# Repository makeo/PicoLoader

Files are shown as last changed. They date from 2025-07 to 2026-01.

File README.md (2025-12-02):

# PicoLoader
This is an ODE-based modchip for the Nintendo GameCube to boot homebrew.\
Its price and functionality are very similar to [PicoBoot](https://github.com/webhdx/PicoBoot) but it has multiple advantages.

Join the [Discord server](https://discord.gg/YtA9aU3BKZ) to get support and discuss the mod!

## How does it work?
This mod works by emulating a disk drive during boot, executing a homebrew app, and afterwards re-enabling the disk drive.\
This is achieved using a flex PCB similar to FlippyDrive.
However, it is not a full optical drive emulator and only allows executing small homebrew apps (e.g. [swiss](https://github.com/emukidid/swiss-gc)) from flash just like PicoBoot.
To access files on an SD card, you need an SDGecko, SD2SP2, or similar adapter, which can be purchased separately.

## Features
- Open source
- You can keep the disk drive
- Simple to boot most homebrew apps using an [online converter](https://makeo.github.io/PicoLoader/converter/)
- No permanent modifications to the GameCube
- [3D printed plug](https://github.com/makeo/PicoLoader/raw/refs/heads/main/mount/Drive_PlugV1.1.stl) for installs without a disk drive 
- Easy to remove
- Running Pico at 200Mhz for better compatibility with clone boards

#### Soldered Variant
- Cheap and easy to get components (Raspberry Pi Pico/Pico 2 + Flex PCB + Diode)
- Readily available
- No soldering directly to the GameCube
- Easy soldering
- Alternative install options: [Panasonic Q](https://github.com/makeo/PicoLoader/wiki/4.-Advanced-Section#panasonic-q-install-option), [low-profile](https://github.com/makeo/PicoLoader/wiki/4.-Advanced-Section#low-profile-install-option)

#### Solderless Variant
- No soldering
- Easily replaceable flex PCB
- Pre-programmed with PicoLoader firmware and [Swiss](https://github.com/emukidid/swiss-gc)
> [!TIP]
> You can buy the solderless and normal variant from [store.makstech.io](https://store.makstech.io/).

## Planned Features
*cricket sound*

## Installation & Documentation
> [!IMPORTANT]
> Please follow the [installation instructions](https://makeo.github.io/PicoLoader/) in the wiki.\
> When not following the instructions, there is a chance of breaking the flex PCB during installation.

Get started by looking at the 📖[Wiki](https://github.com/makeo/PicoLoader/wiki/1.-Home)!

## Gallery

<div style="display: flex; gap: 10px; flex-wrap: nowrap; justify-content: center;">
  
  
  
  
</div>
<div style="display: flex; gap: 10px; flex-wrap: nowrap; justify-content: center;">
  
  
  
  
</div>

## Special Thanks
- [silversteel](https://github.com/silverstee1) for his help, especially for making the flex PCBs and mounts
- [TeamOffBroadway](https://github.com/OffBroadway) for the amazing idea to use a flex PCB to intercept the drive signals
- [Extrems](https://github.com/Extrems), [emukidid](https://github.com/emukidid) and everyone involved in creating Swiss
- [novenary (9ary)](https://github.com/9ary) for gekkoboot

## Acknowledgements
The source of [gbi.hdr](https://github.com/makeo/PicoLoader/blob/main/picoloader/data/gbi.hdr) and [gbi_disable_ipl.hdr](https://github.com/makeo/PicoLoader/blob/main/picoloader/data/gbi_disable_ipl.hdr) is licensed under GPL-2.0 and available [here](https://github.com/makeo/cubeboot-tools)

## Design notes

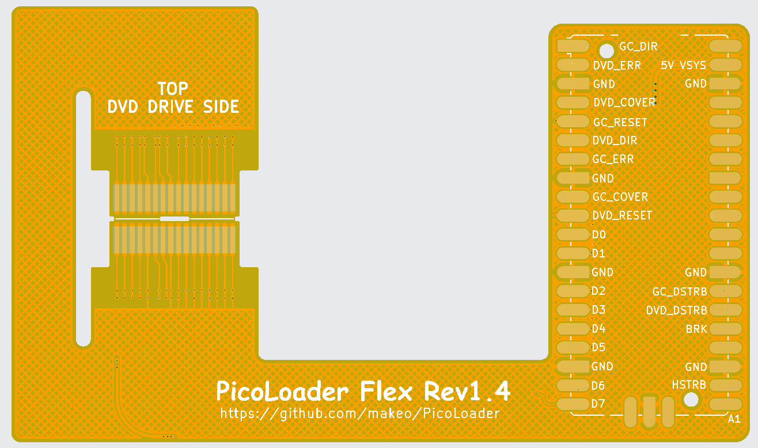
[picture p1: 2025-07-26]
flex/InterposerFlex/Kicad/InterposerFlex2.png

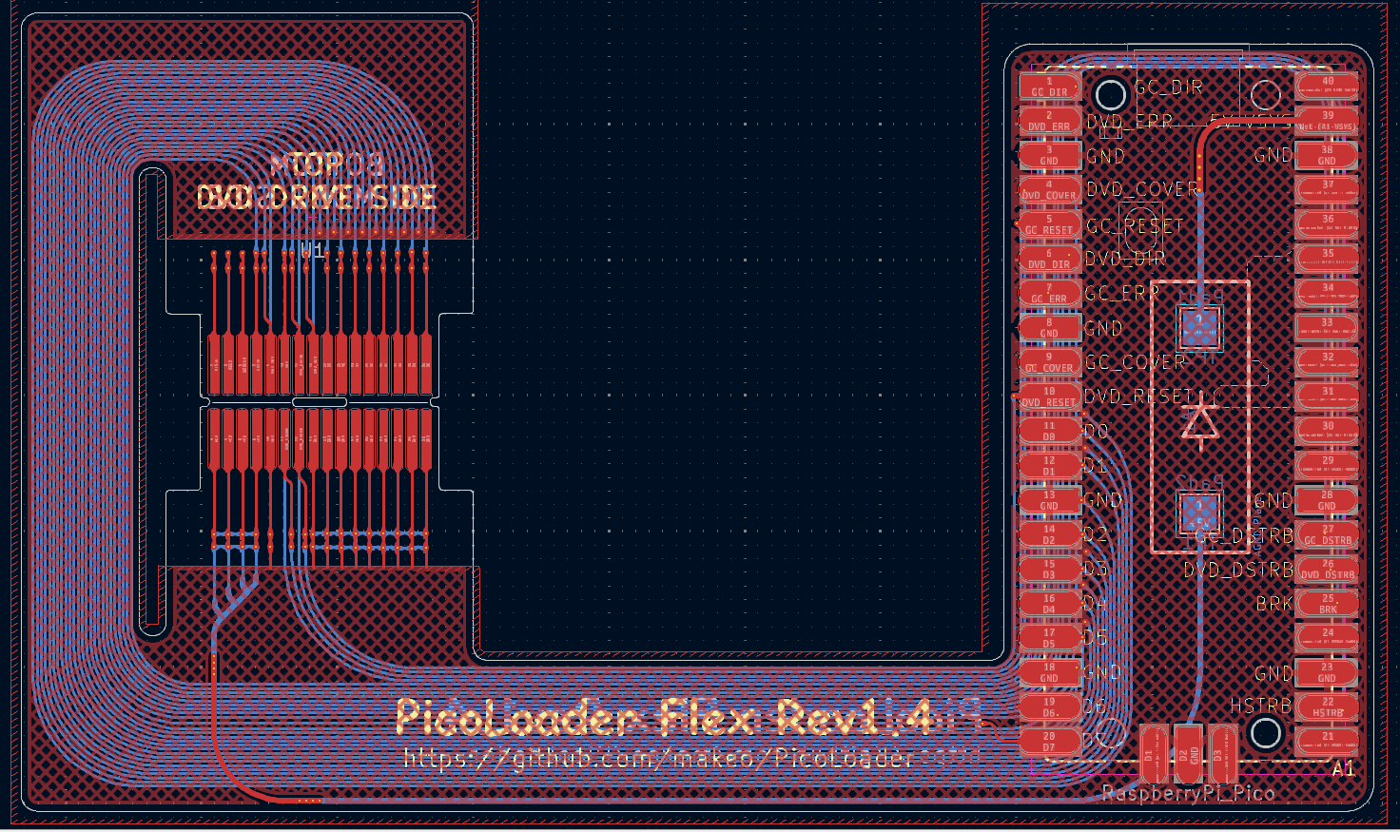
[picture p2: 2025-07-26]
flex/InterposerFlex/Kicad/InterposerFlex.png

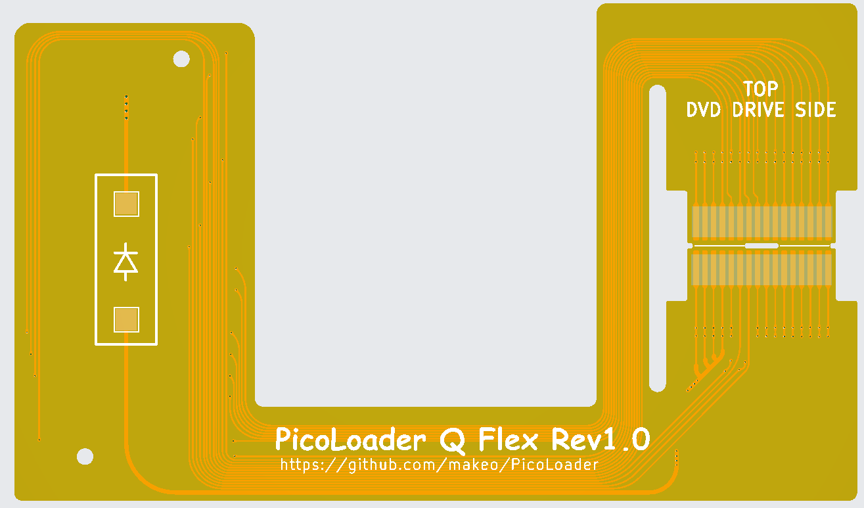
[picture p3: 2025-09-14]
flex/PanasonicQFlex/Kicad/FlexQ_1.png

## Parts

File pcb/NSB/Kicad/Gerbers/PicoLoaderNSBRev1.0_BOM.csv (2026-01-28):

Designator | Footprint | Quantity | Value | LCSC Part #
C1, C10, C11, C12, C13, C14, C5, C6, C7 | 0402 | 9 | 100nF | C1525
C15, C16, C8, C9 | 0402 | 4 | 1uF | C52923
C2, C3 | 0402 | 2 | 33pF | C1562
D1, D2 | D_SOD-323 | 2 | 1N5819WS | C191023
D3 | 0805 | 1 | LED | C2297
J1 | CONN_502598-3993_MOL | 1 | 5025983993 | C505359
J3 | USB_C_Receptacle_Palconn_UTC16-G | 1 | USB_C_Receptacle_USB2.0 | C165948
J4 | TestPoint_Pad_D1.0mm | 1 | +
J5 | TestPoint_Pad_D1.0mm | 1 | D
J6 | TestPoint_Pad_D1.0mm | 1 | C
J7 | TestPoint_Pad_D1.0mm | 1 | G
R1, R6, R7 | 0402 | 3 | 1k | C11702
R2, R3 | 0402 | 2 | 5.1k | C25905
R4, R5 | 0402 | 2 | 22R | C25092
S1 | TS-1187A-B-A-B | 1 | TS-1187A-B-A-B | C318884
TP1, TP2, TP3, TP4, TP5, TP6, TP7, TP8, TP9 | TestPoint_Pad_D1.0mm | 9 | TestPoint
U1 | QFN-56-1EP_7x7mm_P0.4mm_EP3.2x3.2mm | 1 | RP2040 | C2040
U2 | SOIC-8_5.3x5.3mm_P1.27mm | 1 | W25Q128JVS | C97521
U3 | SOT-23 | 1 | XC6206P332MR | C5446
Y1 | Crystal_SMD_3225-4Pin_3.2x2.5mm | 1 | 12 Mhz | C9002

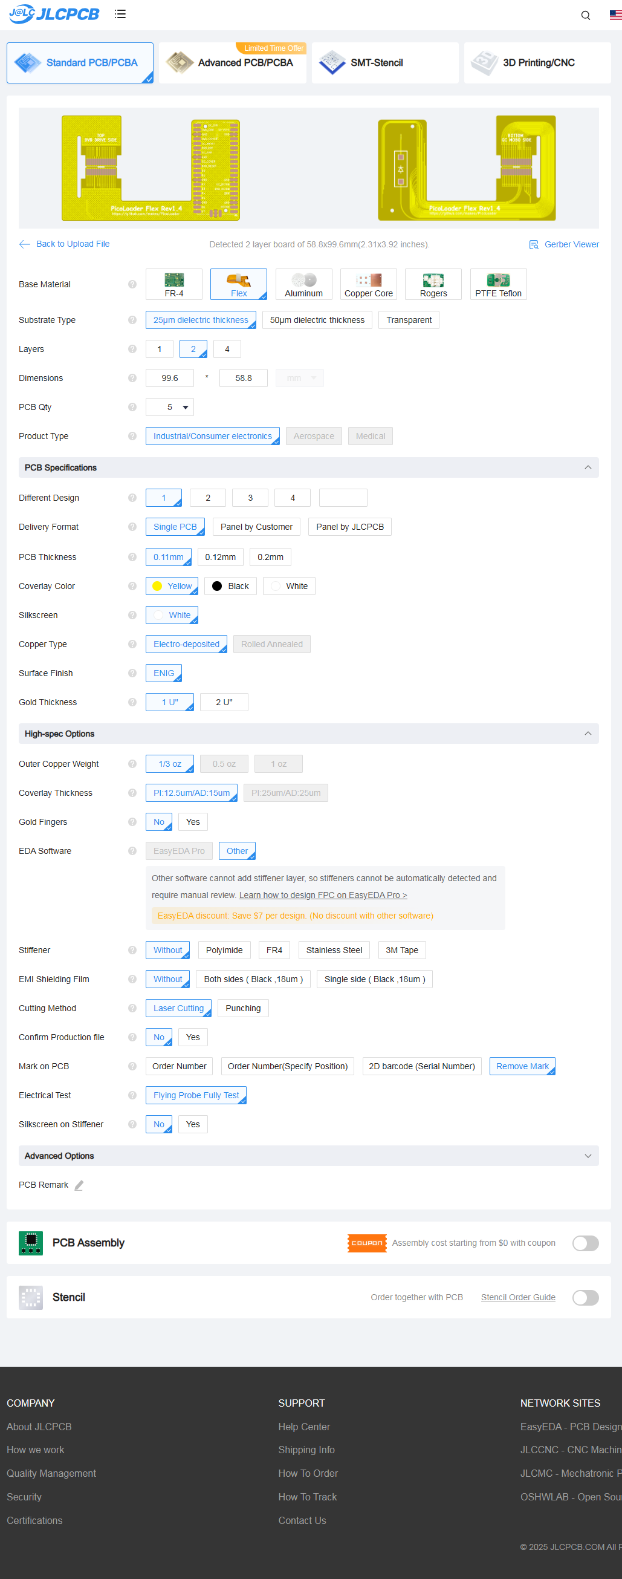
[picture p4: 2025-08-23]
flex/InterposerFlex/JLCPCB Order Settings.png

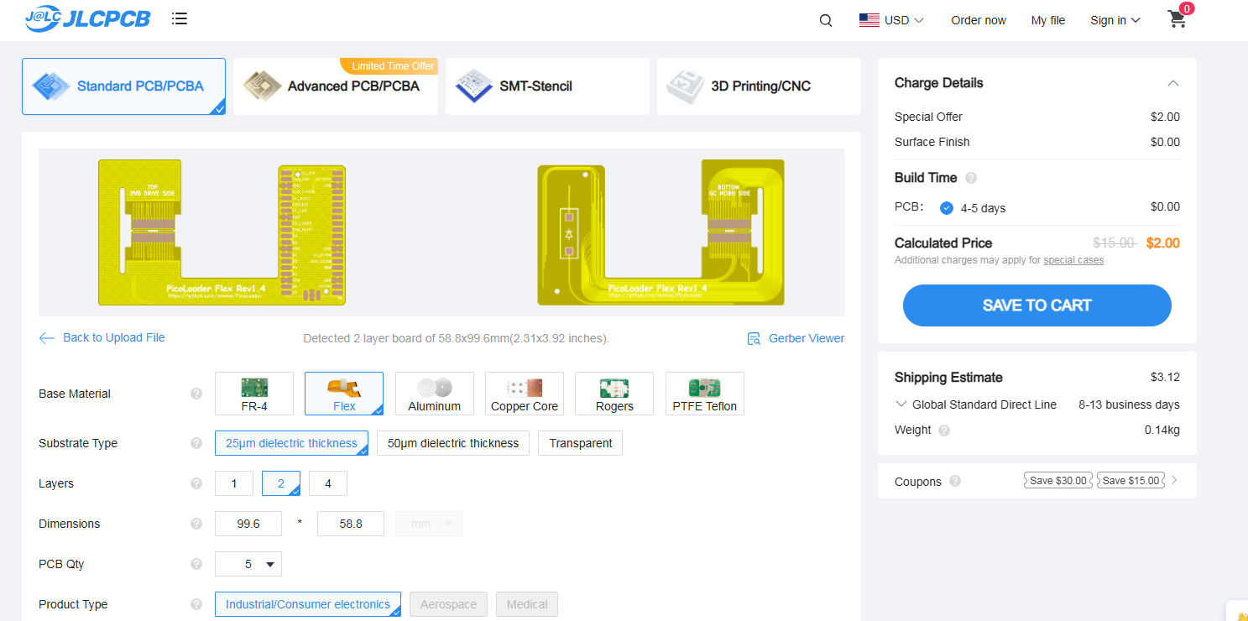
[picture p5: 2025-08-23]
flex/InterposerFlex/JLCPCB Order Estimate Price.png

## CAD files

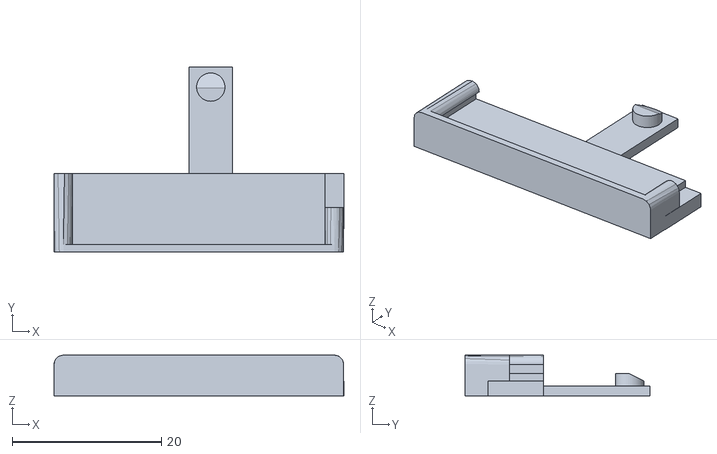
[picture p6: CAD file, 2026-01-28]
mount/QNSB_TopV1.1.stl
38.8 x 24.8 x 5.47

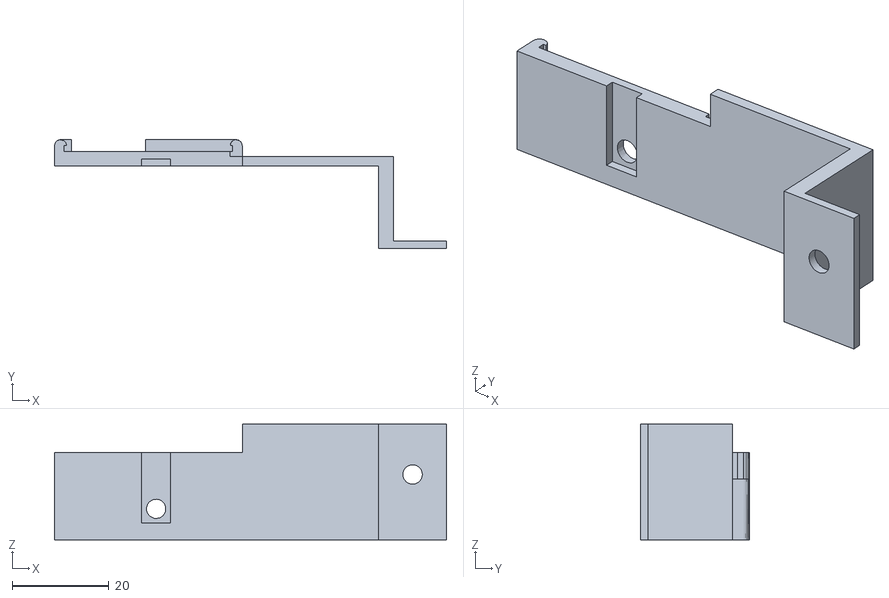
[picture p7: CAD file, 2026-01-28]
mount/QNSB_BottomV1.stl
81.0 x 22.5 x 23.9

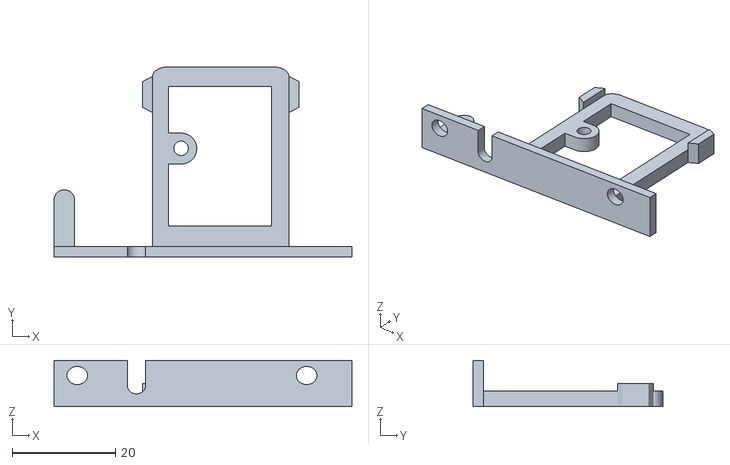
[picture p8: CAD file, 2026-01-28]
mount/NSB_MountV1.7.stl
57.8 x 36.8 x 9.00

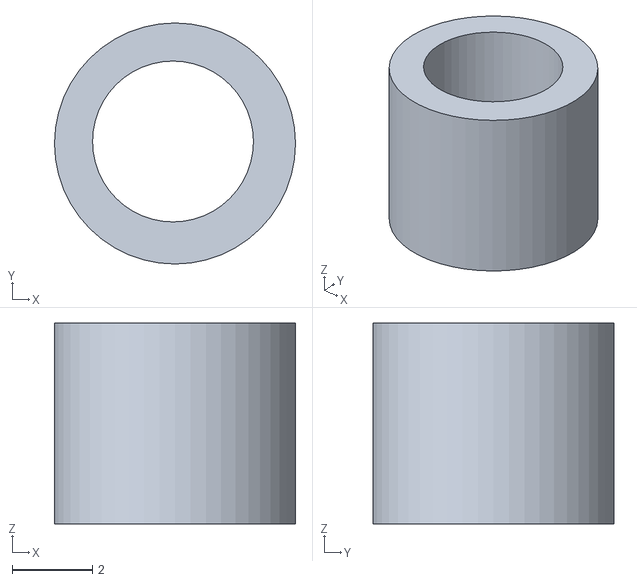
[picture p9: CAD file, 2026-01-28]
mount/NSB_SpacerV1.2.stl
6.00 x 6.00 x 5.00

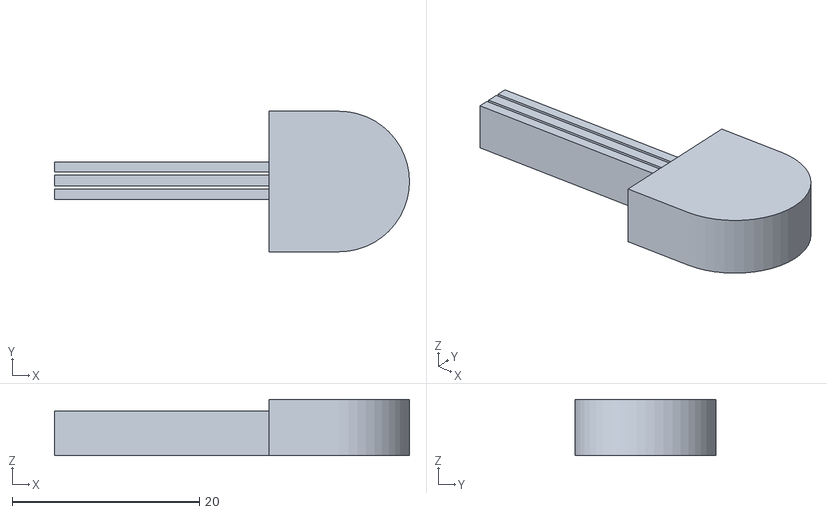
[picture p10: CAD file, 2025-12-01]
mount/Fold_KeyV1.2.stl
37.9 x 15.0 x 6.00

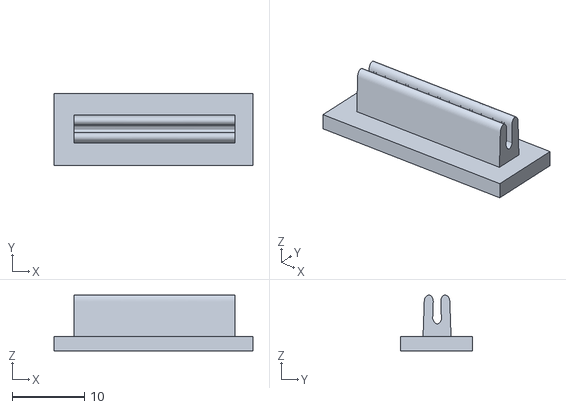
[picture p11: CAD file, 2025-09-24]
mount/Drive_PlugV1.1.stl
27.5 x 10.0 x 7.72

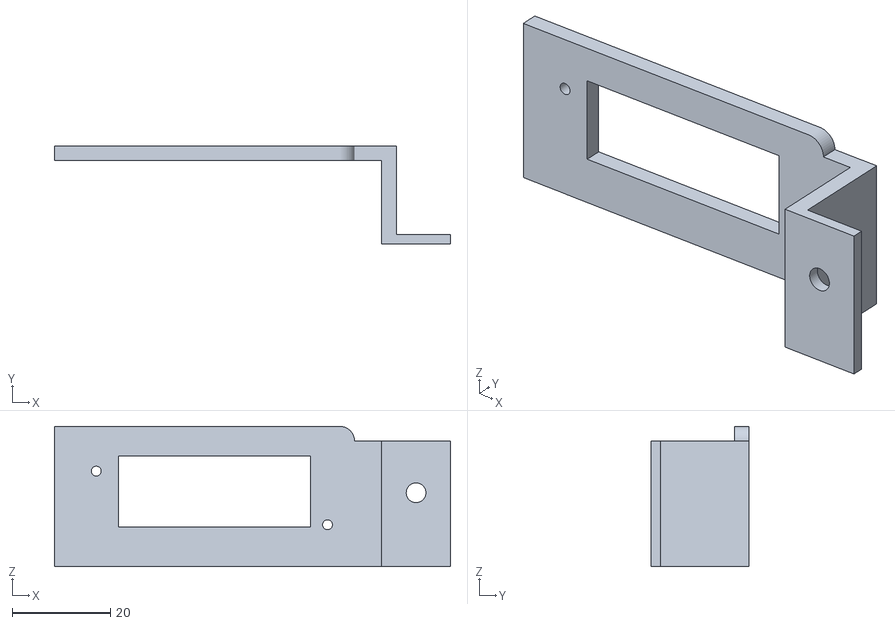
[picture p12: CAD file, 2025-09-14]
mount/Panasonic_Q_MountV1.2.stl
80.5 x 20.0 x 28.5

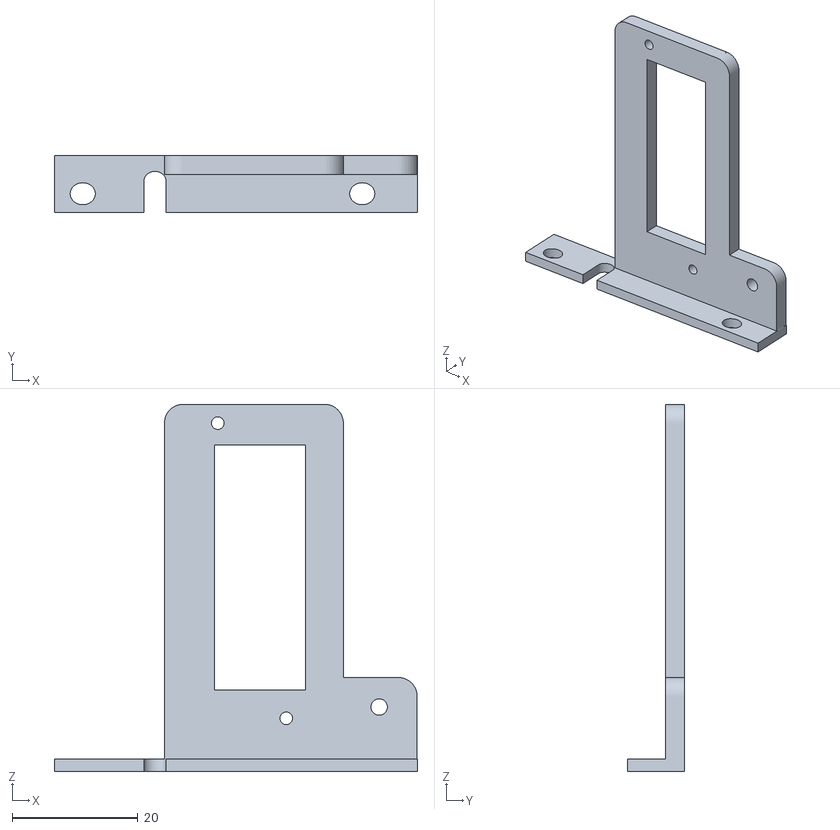
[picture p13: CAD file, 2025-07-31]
mount/Interposer_Mountv1.7.stl
57.8 x 9.00 x 58.5

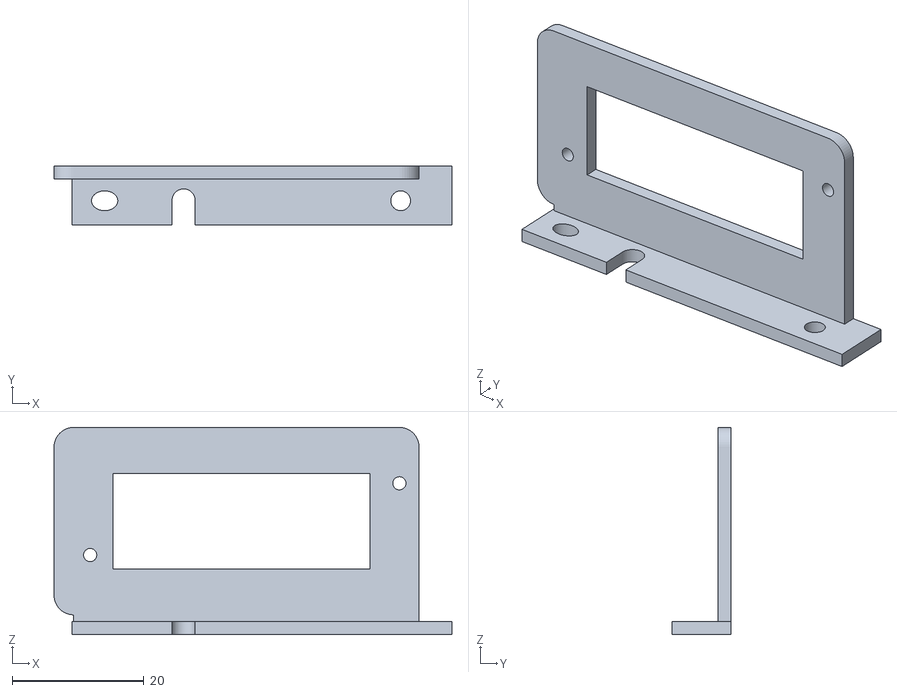
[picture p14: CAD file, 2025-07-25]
mount/SolderFlex_Mount_Horizontal_v1.2.stl
60.5 x 9.00 x 31.5

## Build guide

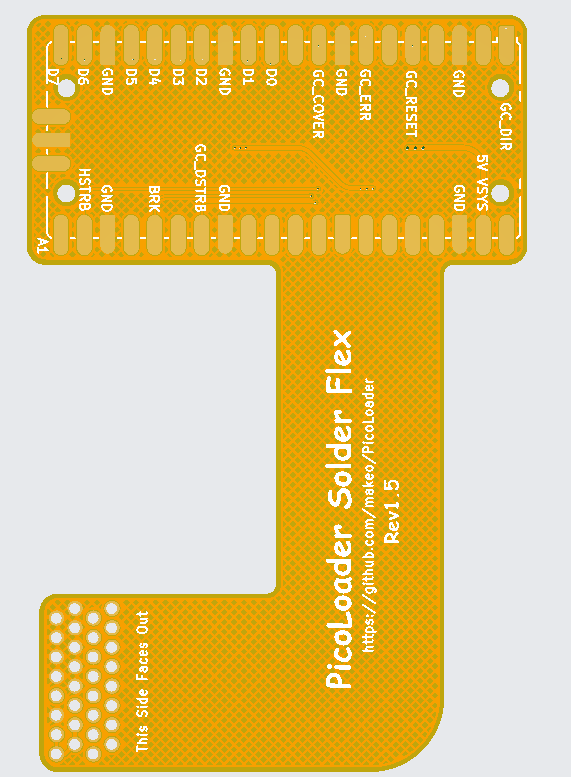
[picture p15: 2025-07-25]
flex/SolderFlex/Kicad/SolderFlex2.png

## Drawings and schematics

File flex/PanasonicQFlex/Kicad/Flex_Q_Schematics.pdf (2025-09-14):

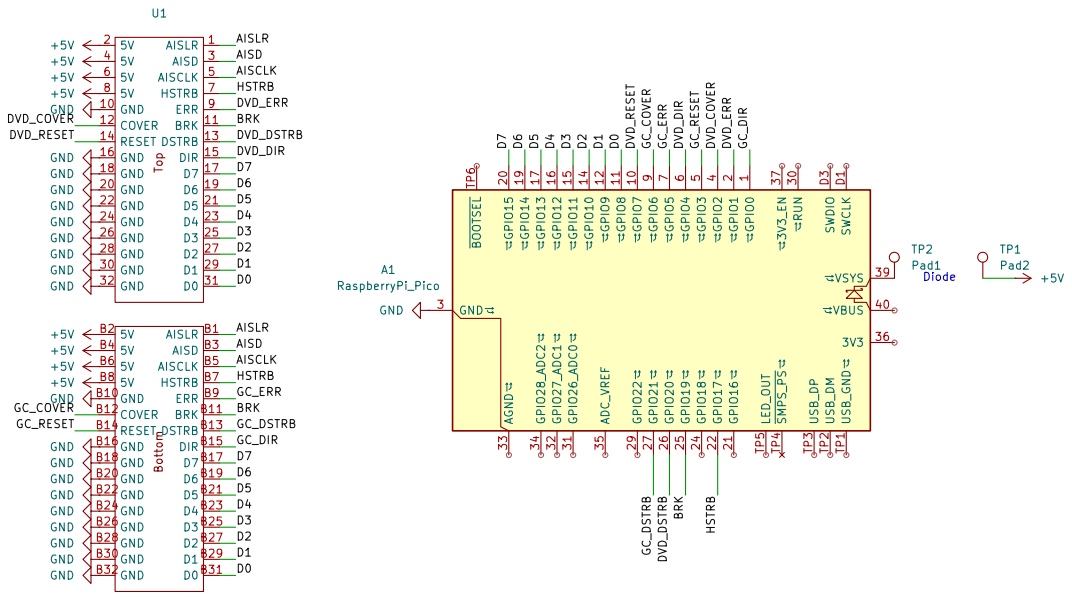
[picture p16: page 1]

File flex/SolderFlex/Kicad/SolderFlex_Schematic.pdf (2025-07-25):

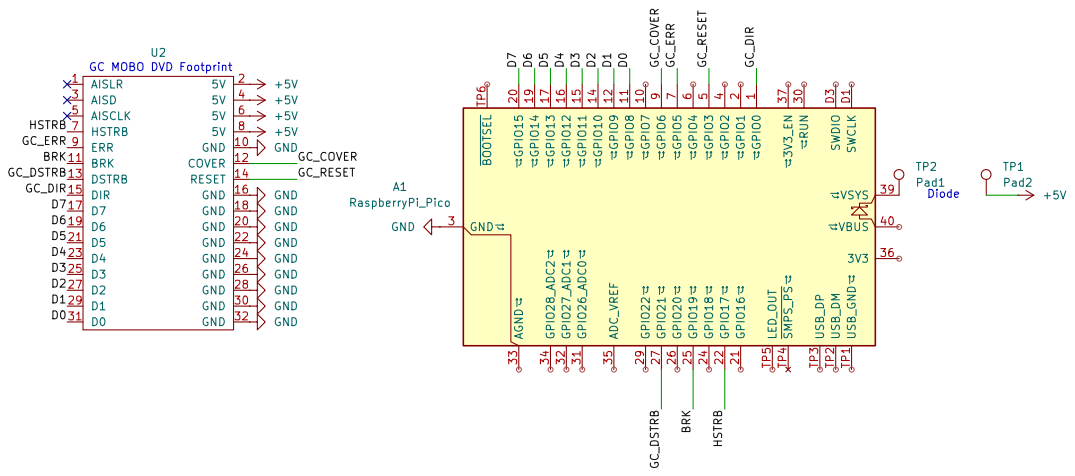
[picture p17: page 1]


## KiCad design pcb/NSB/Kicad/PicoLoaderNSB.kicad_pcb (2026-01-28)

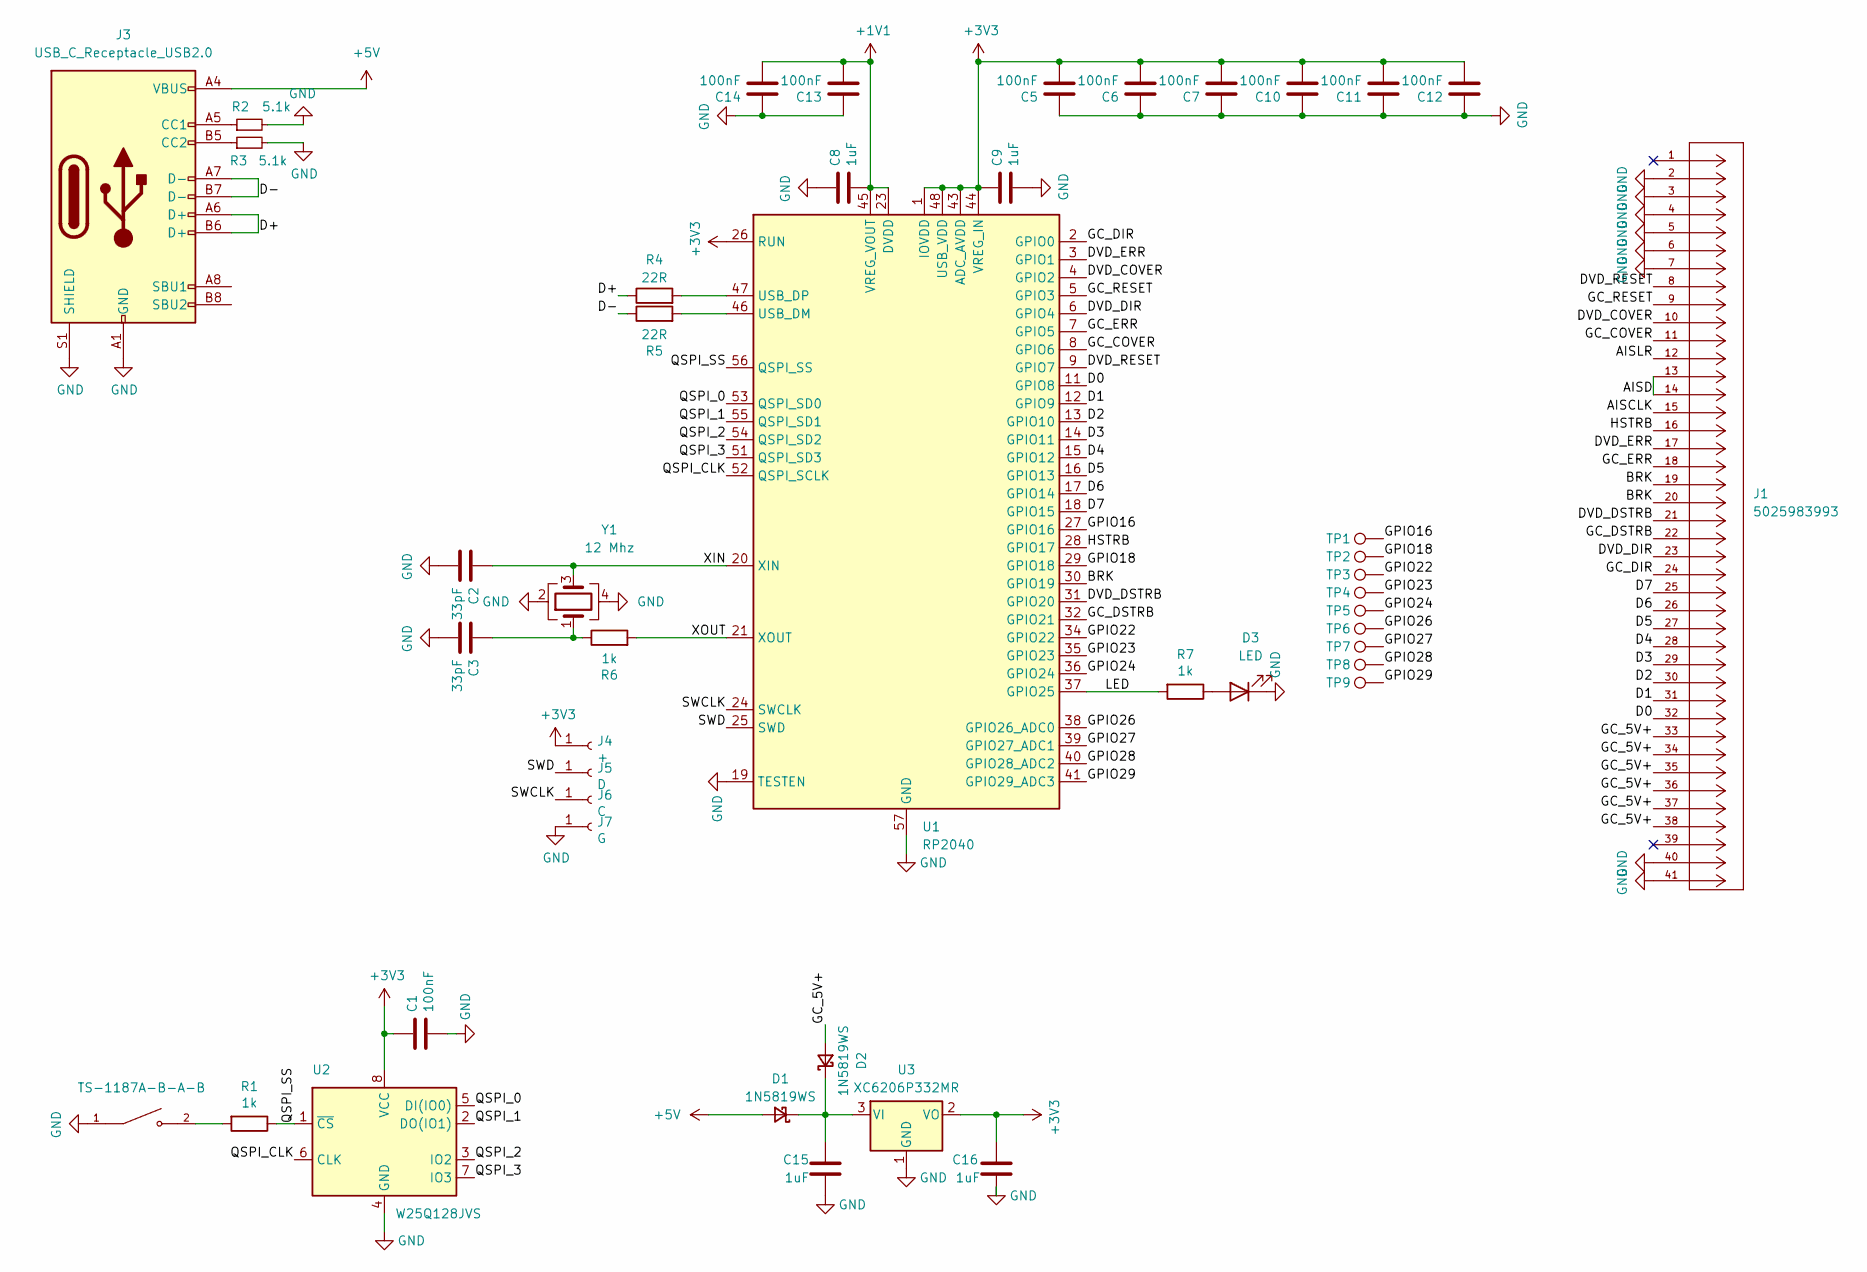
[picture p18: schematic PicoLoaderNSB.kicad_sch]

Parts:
C1, C5, C6, C7, C10, C11, C12, C13, C14: 100nF; C_0402_1005Metric; LCSC C1525
C2, C3: 33pF; C_0402_1005Metric; LCSC C1562
C8, C9, C15, C16: 1uF; C_0402_1005Metric; LCSC C52923
D1, D2: 1N5819WS; D_SOD-323; LCSC C191023
D3: LED; LED_0805_2012Metric; LCSC C2297
J1: 5025983993; CONN_502598-3993_MOL; MANUFACTURER_PART_NUMBER 5025983993; LCSC C505359
J3: USB_C_Receptacle_USB2.0; USB_C_Receptacle_Palconn_UTC16-G; LCSC C165948
J4: +; TestPoint_Pad_D1.0mm
J5: D; TestPoint_Pad_D1.0mm
J6: C; TestPoint_Pad_D1.0mm
J7: G; TestPoint_Pad_D1.0mm
R1, R6, R7: 1k; R_0402_1005Metric; LCSC C11702
R2, R3: 5.1k; R_0402_1005Metric; LCSC C25905
R4, R5: 22R; R_0402_1005Metric; LCSC C25092
S1: TS-1187A-B-A-B; PARTREV A0; LCSC C318884
TP1, TP2, TP3, TP4, TP5, TP6, TP7, TP8, TP9: TestPoint; TestPoint_Pad_D1.0mm
U1: RP2040; QFN-56-1EP_7x7mm_P0.4mm_EP3.2x3.2mm; LCSC C2040
U2: W25Q128JVS; SOIC-8_5.3x5.3mm_P1.27mm; LCSC C97521
U3: XC6206P332MR; SOT-23; LCSC C5446
Y1: 12 Mhz; Crystal_SMD_3225-4Pin_3.2x2.5mm; LCSC C9002

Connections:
+1V1: C8.2, C13.2, C14.2, U1.23 (DVDD), U1.45 (VREG_VOUT), U1.50 (DVDD)
+3V3: C1.1, C5.2, C6.2, C7.2, C9.1, C10.2, C11.2, C12.2, C16.1, J4.1, U1.1 (IOVDD), U1.10 (IOVDD), U1.22 (IOVDD), U1.26 (RUN), U1.33 (IOVDD), U1.42 (IOVDD), U1.43 (ADC_AVDD), U1.44 (VREG_IN), U1.48 (USB_VDD), U1.49 (IOVDD), U2.8 (VCC), U3.2 (VO)
+5V: D1.2 (A), J3.A4 (VBUS), J3.A9 (VBUS), J3.B4 (VBUS), J3.B9 (VBUS)
/AISCLK: J1.15
/AISD: J1.13, J1.14
/AISLR: J1.12
/BRK: J1.19, J1.20, U1.30 (GPIO19)
/D0: J1.32, U1.11 (GPIO8)
/D1: J1.31, U1.12 (GPIO9)
/D2: J1.30, U1.13 (GPIO10)
/D3: J1.29, U1.14 (GPIO11)
/D4: J1.28, U1.15 (GPIO12)
/D5: J1.27, U1.16 (GPIO13)
/D6: J1.26, U1.17 (GPIO14)
/D7: J1.25, U1.18 (GPIO15)
/D+: J3.A6 (D+), J3.B6 (D+), R4.1
/D-: J3.A7 (D-), J3.B7 (D-), R5.1
/DVD_COVER: J1.10, U1.4 (GPIO2)
/DVD_DIR: J1.23, U1.6 (GPIO4)
/DVD_DSTRB: J1.21, U1.31 (GPIO20)
/DVD_ERR: J1.17, U1.3 (GPIO1)
/DVD_RESET: J1.8, U1.9 (GPIO7)
/GC_5V+: D2.2 (A), J1.33, J1.34, J1.35, J1.36, J1.37, J1.38
/GC_COVER: J1.11, U1.8 (GPIO6)
/GC_DIR: J1.24, U1.2 (GPIO0)
/GC_DSTRB: J1.22, U1.32 (GPIO21)
/GC_ERR: J1.18, U1.7 (GPIO5)
/GC_RESET: J1.9, U1.5 (GPIO3)
/GPIO16: TP1.1, U1.27 (GPIO16)
/GPIO18: TP2.1, U1.29 (GPIO18)
/GPIO22: TP3.1, U1.34 (GPIO22)
/GPIO23: TP4.1, U1.35 (GPIO23)
/GPIO24: TP5.1, U1.36 (GPIO24)
/GPIO26: TP6.1, U1.38 (GPIO26_ADC0)
/GPIO27: TP7.1, U1.39 (GPIO27_ADC1)
/GPIO28: TP8.1, U1.40 (GPIO28_ADC2)
/GPIO29: TP9.1, U1.41 (GPIO29_ADC3)
/HSTRB: J1.16, U1.28 (GPIO17)
/LED: R7.2, U1.37 (GPIO25)
/QSPI_0: U1.53 (QSPI_SD0), U2.5 (DI(IO0))
/QSPI_1: U1.55 (QSPI_SD1), U2.2 (DO(IO1))
/QSPI_2: U1.54 (QSPI_SD2), U2.3 (IO2)
/QSPI_3: U1.51 (QSPI_SD3), U2.7 (IO3)
/QSPI_CLK: U1.52 (QSPI_SCLK), U2.6 (CLK)
/QSPI_SS: R1.1, U1.56 (QSPI_SS), U2.1 (~CS)
/SWCLK: J6.1, U1.24 (SWCLK)
/SWD: J5.1, U1.25 (SWD)
/XIN: C2.1, U1.20 (XIN), Y1.3
/XOUT: R6.2, U1.21 (XOUT)
GND: C1.2, C2.2, C3.2, C5.1, C6.1, C7.1, C8.1, C9.2, C10.1, C11.1, C12.1, C13.1, C14.1, C15.2, C16.2, D3.1 (K), J1.2, J1.3, J1.4, J1.5, J1.6, J1.7, J1.40, J1.41, J3.A1 (GND), J3.A12 (GND), J3.B1 (GND), J3.B12 (GND), J3.S1 (SHIELD), J7.1, R2.2, R3.2, S1.1, U1.19 (TESTEN), U1.57 (GND), U2.4 (GND), U3.1 (GND), Y1.2, Y1.4
unnamed: C3.1, R6.1, Y1.1
unnamed: C15.1, D1.1 (K), D2.1 (K), U3.3 (VI)
unnamed: D3.2 (A), R7.1
unnamed: J3.A5 (CC1), R2.1
unnamed: J3.B5 (CC2), R3.1
unnamed: R1.2, S1.2
unnamed: R5.2, U1.46 (USB_DM)
unnamed: R4.2, U1.47 (USB_DP)

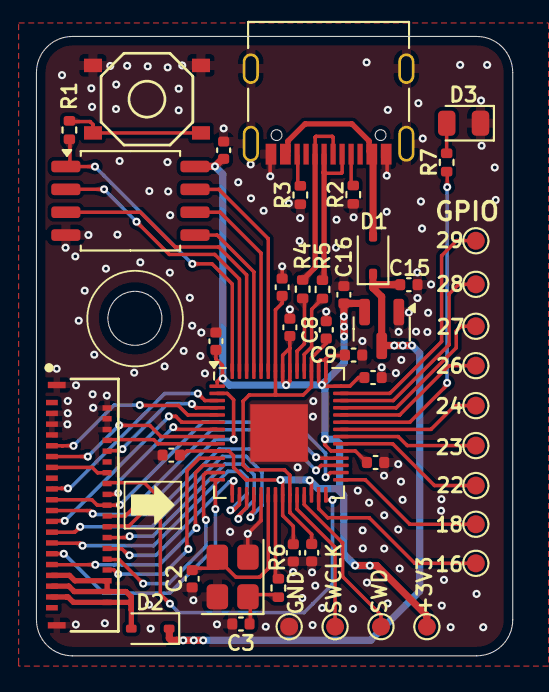
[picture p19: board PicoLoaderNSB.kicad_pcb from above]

Board: 2 copper layers, 26.5 x 34.4 mm, 45 parts (0 on the bottom side), 56 nets.

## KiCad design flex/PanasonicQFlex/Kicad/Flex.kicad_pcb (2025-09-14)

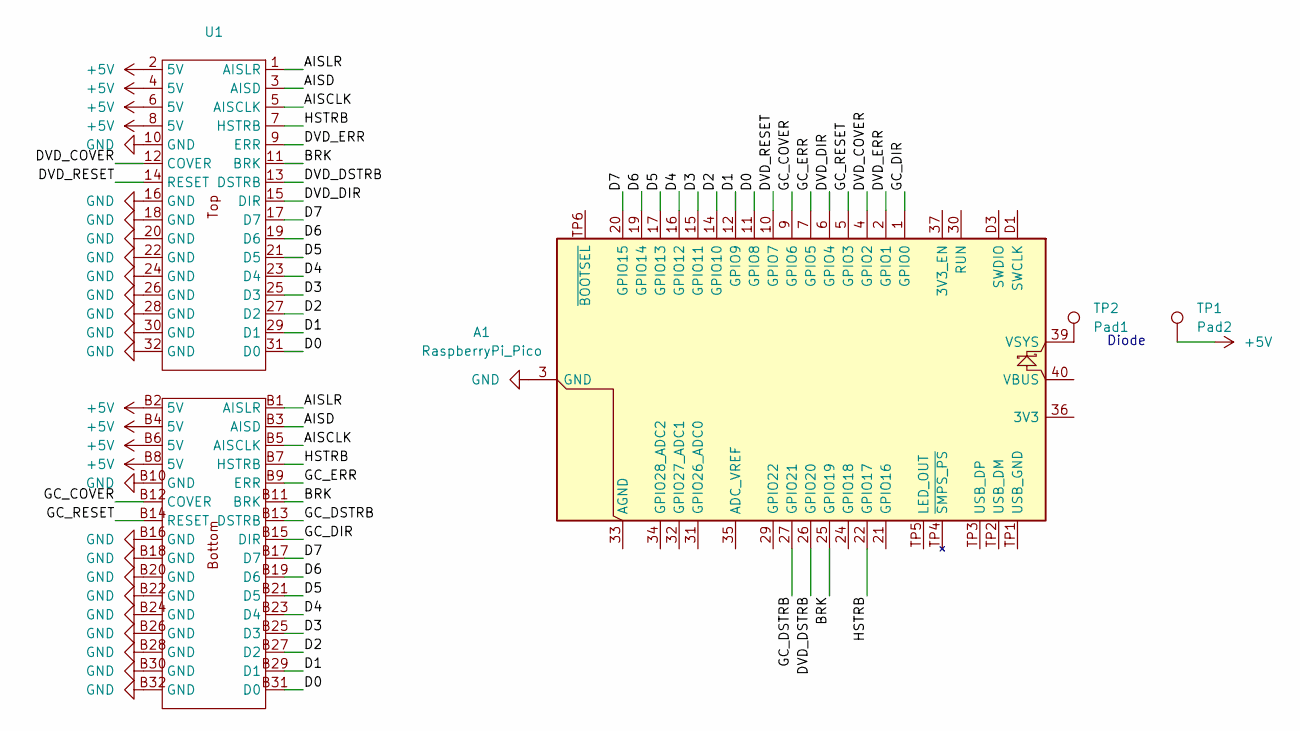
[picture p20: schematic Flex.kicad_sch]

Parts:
A1: RaspberryPi_Pico; RaspberryPi_Pico_SMD
TP1: Pad2; TestPoint_Pad_2.5x2.5mm
TP2: Pad1; TestPoint_Pad_2.5x2.5mm
U1: DVDCN_FLEX_PADS

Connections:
+5V: TP1.1, U1.2 (5V), U1.4 (5V), U1.6 (5V), U1.8 (5V), U1.B2 (5V), U1.B4 (5V), U1.B6 (5V), U1.B8 (5V)
/AISCLK: U1.5 (AISCLK), U1.B5 (AISCLK)
/AISD: U1.3 (AISD), U1.B3 (AISD)
/AISLR: U1.1 (AISLR), U1.B1 (AISLR)
/BRK: A1.25 (GPIO19), U1.11 (BRK), U1.B11 (BRK)
/D0: A1.11 (GPIO8), U1.31 (D0), U1.B31 (D0)
/D1: A1.12 (GPIO9), U1.29 (D1), U1.B29 (D1)
/D2: A1.14 (GPIO10), U1.27 (D2), U1.B27 (D2)
/D3: A1.15 (GPIO11), U1.25 (D3), U1.B25 (D3)
/D4: A1.16 (GPIO12), U1.23 (D4), U1.B23 (D4)
/D5: A1.17 (GPIO13), U1.21 (D5), U1.B21 (D5)
/D6: A1.19 (GPIO14), U1.19 (D6), U1.B19 (D6)
/D7: A1.20 (GPIO15), U1.17 (D7), U1.B17 (D7)
/DVD_COVER: A1.4 (GPIO2), U1.12 (COVER)
/DVD_DIR: A1.6 (GPIO4), U1.15 (DIR)
/DVD_DSTRB: A1.26 (GPIO20), U1.13 (DSTRB)
/DVD_ERR: A1.2 (GPIO1), U1.9 (ERR)
/DVD_RESET: A1.10 (GPIO7), U1.14 (RESET)
/GC_COVER: A1.9 (GPIO6), U1.B12 (COVER)
/GC_DIR: A1.1 (GPIO0), U1.B15 (DIR)
/GC_DSTRB: A1.27 (GPIO21), U1.B13 (DSTRB)
/GC_ERR: A1.7 (GPIO5), U1.B9 (ERR)
/GC_RESET: A1.5 (GPIO3), U1.B14 (RESET)
/HSTRB: A1.22 (GPIO17), U1.7 (HSTRB), U1.B7 (HSTRB)
GND: A1.3 (GND), A1.8 (GND), A1.13 (GND), A1.18 (GND), A1.23 (GND), A1.28 (GND), A1.38 (GND), A1.D2 (GND), U1.10 (GND), U1.16 (GND), U1.18 (GND), U1.20 (GND), U1.22 (GND), U1.24 (GND), U1.26 (GND), U1.28 (GND), U1.30 (GND), U1.32 (GND), U1.B10 (GND), U1.B16 (GND), U1.B18 (GND), U1.B20 (GND), U1.B22 (GND), U1.B24 (GND), U1.B26 (GND), U1.B28 (GND), U1.B30 (GND), U1.B32 (GND)
unnamed: A1.39 (VSYS), TP2.1

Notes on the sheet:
Diode

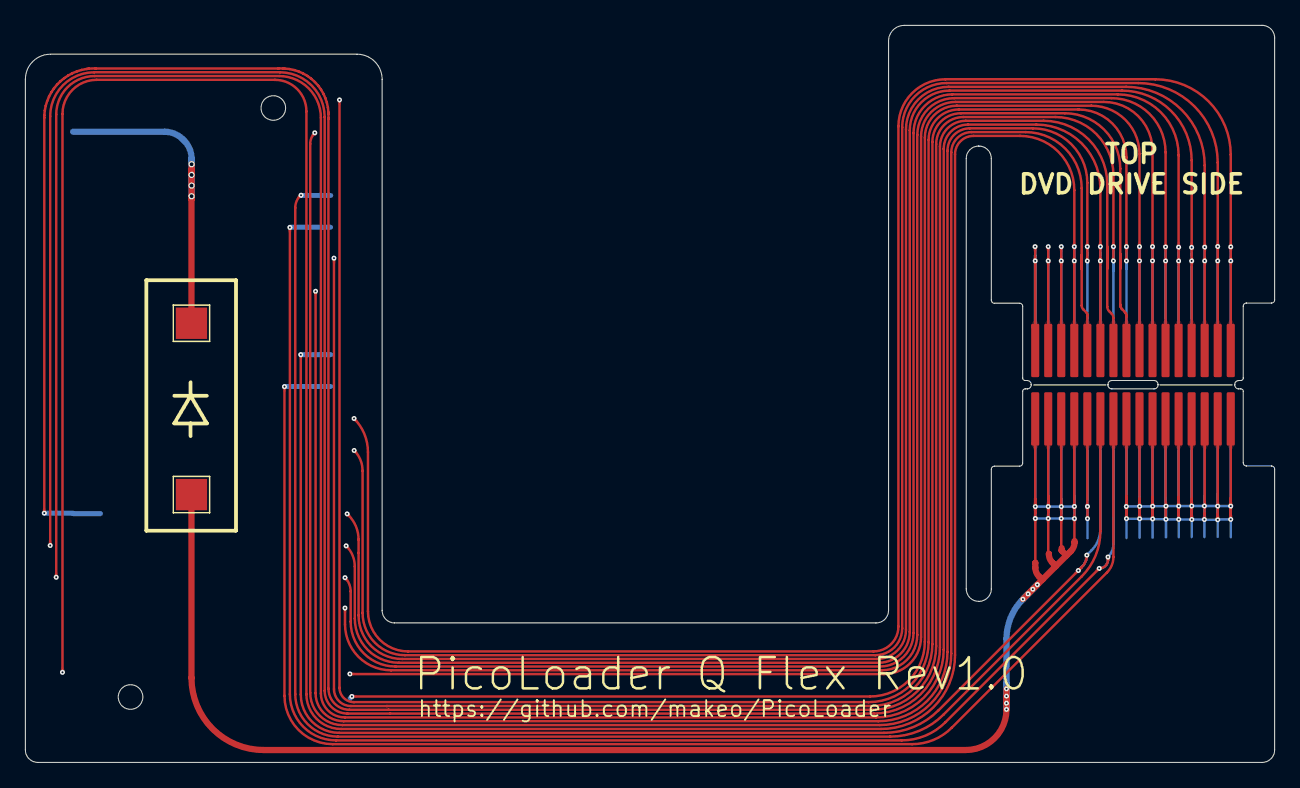
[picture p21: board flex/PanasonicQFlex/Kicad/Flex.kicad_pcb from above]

Board: 2 copper layers, 99.7 x 58.8 mm, 4 parts (1 on the bottom side), 26 nets.

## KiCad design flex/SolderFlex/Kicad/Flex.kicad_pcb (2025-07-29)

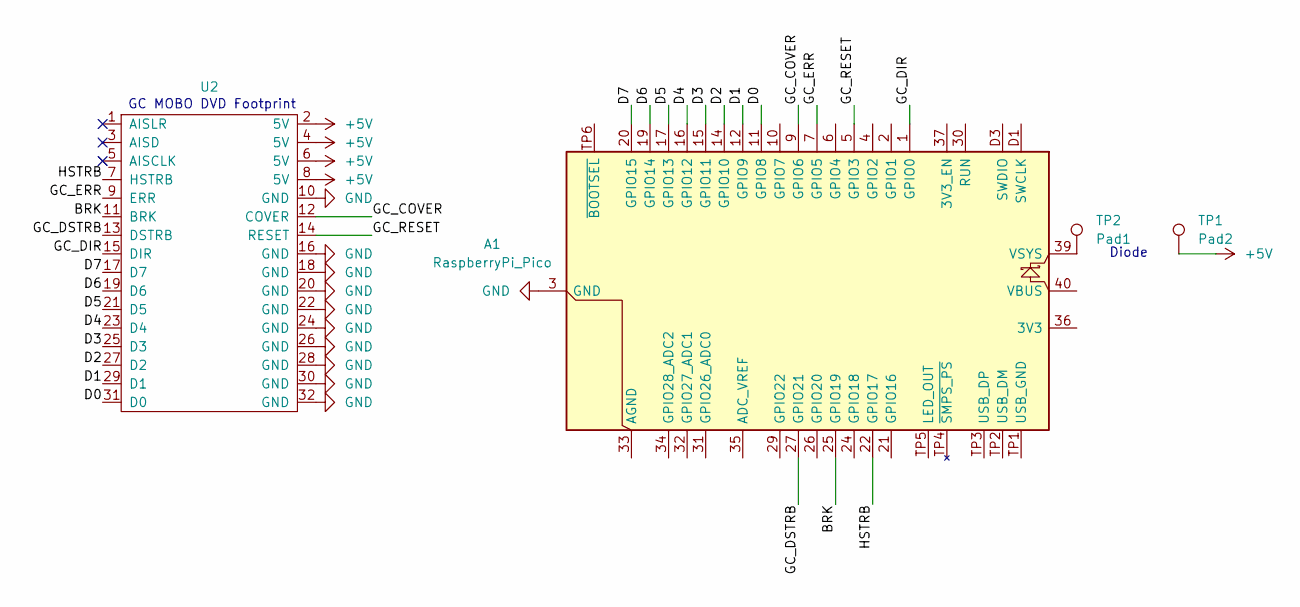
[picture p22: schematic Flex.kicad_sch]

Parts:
A1: RaspberryPi_Pico; RaspberryPi_Pico_SMD
TP1: Pad2; TestPoint_Pad_2.5x2.5mm
TP2: Pad1; TestPoint_Pad_2.5x2.5mm
U2: GC_MOBO_DVD_CN

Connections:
+5V: TP1.1, U2.2 (5V), U2.4 (5V), U2.6 (5V), U2.8 (5V)
/BRK: A1.25 (GPIO19), U2.11 (BRK)
/D0: A1.11 (GPIO8), U2.31 (D0)
/D1: A1.12 (GPIO9), U2.29 (D1)
/D2: A1.14 (GPIO10), U2.27 (D2)
/D3: A1.15 (GPIO11), U2.25 (D3)
/D4: A1.16 (GPIO12), U2.23 (D4)
/D5: A1.17 (GPIO13), U2.21 (D5)
/D6: A1.19 (GPIO14), U2.19 (D6)
/D7: A1.20 (GPIO15), U2.17 (D7)
/GC_COVER: A1.9 (GPIO6), U2.12 (COVER)
/GC_DIR: A1.1 (GPIO0), U2.15 (DIR)
/GC_DSTRB: A1.27 (GPIO21), U2.13 (DSTRB)
/GC_ERR: A1.7 (GPIO5), U2.9 (ERR)
/GC_RESET: A1.5 (GPIO3), U2.14 (RESET)
/HSTRB: A1.22 (GPIO17), U2.7 (HSTRB)
GND: A1.3 (GND), A1.8 (GND), A1.13 (GND), A1.18 (GND), A1.23 (GND), A1.28 (GND), A1.38 (GND), A1.D2 (GND), U2.10 (GND), U2.16 (GND), U2.18 (GND), U2.20 (GND), U2.22 (GND), U2.24 (GND), U2.26 (GND), U2.28 (GND), U2.30 (GND), U2.32 (GND)
unnamed: A1.39 (VSYS), TP2.1

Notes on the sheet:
GC MOBO DVD Footprint
Diode

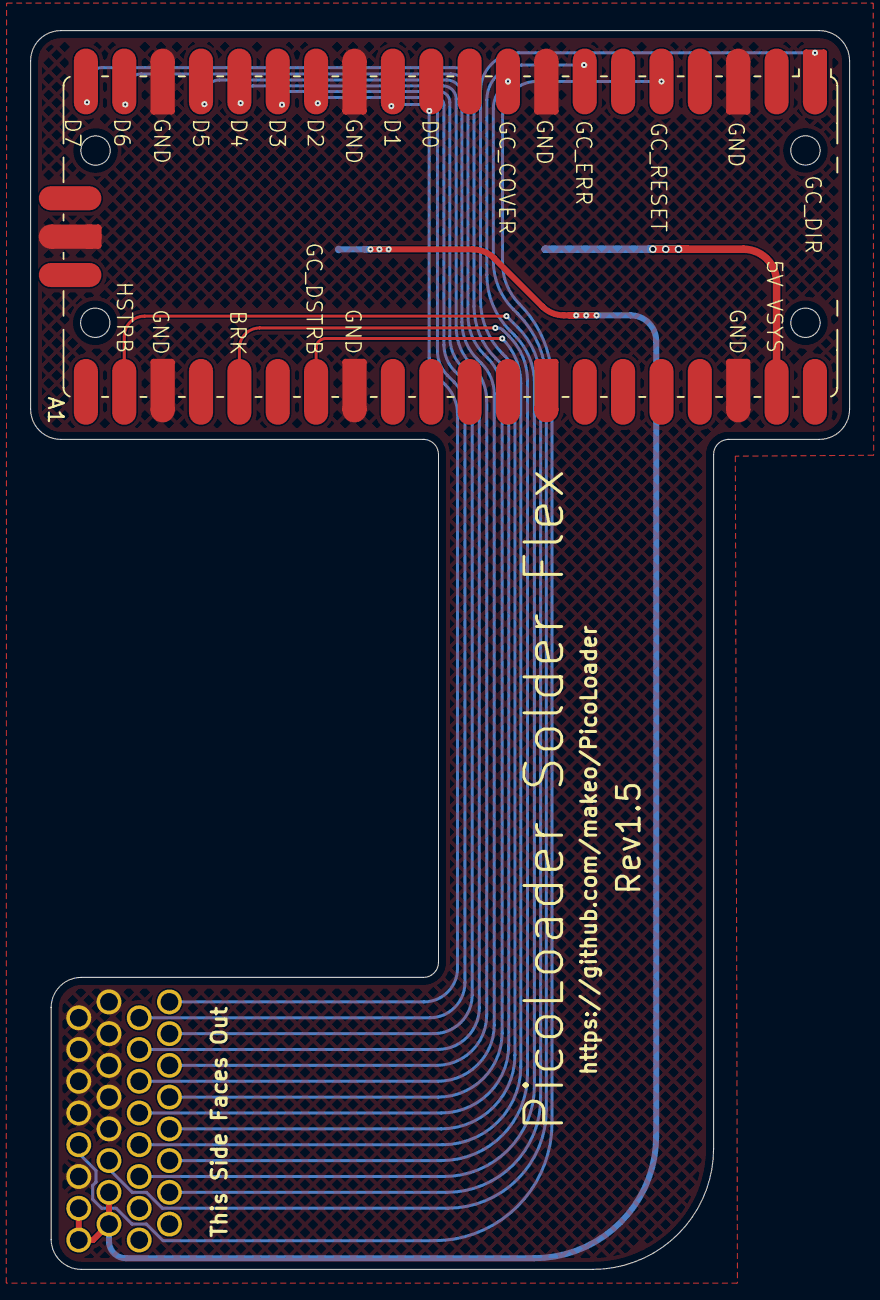
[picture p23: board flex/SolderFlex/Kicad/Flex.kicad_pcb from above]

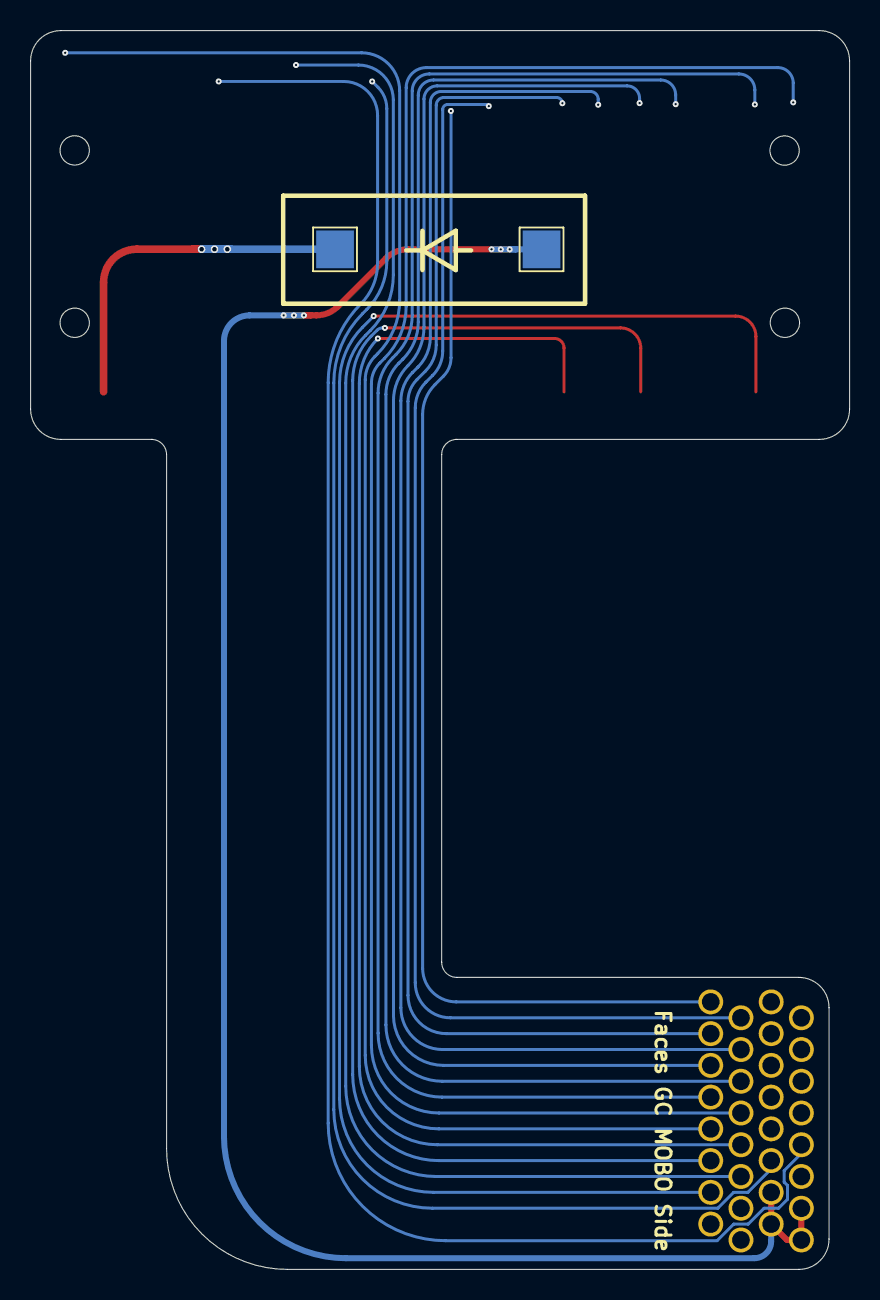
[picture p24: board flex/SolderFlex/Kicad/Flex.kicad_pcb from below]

Board: 2 copper layers, 54.2 x 82.0 mm, 4 parts (3 on the bottom side), 18 nets.

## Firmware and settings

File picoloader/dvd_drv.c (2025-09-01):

#include "dvd_drv.h"

#include <stdio.h>
#include <hardware/pio.h>
#include <hardware/gpio.h>
#include <hardware/dma.h>
#include <hardware/clocks.h>
#include <pico/stdlib.h>
#include "drive_interface.pio.h"
#include "dvd.h"

#define PIO_RECV_SM 0
#define PIO_SEND_SM 1
#define PIO_DIR_SM 2
#define PIO_PASSTHROUGH_SM 3

static int send_chan;

void dvd_drv_init_gpios();
void dvd_drv_init_pio();

void dvd_drv_clear_state();

void dvd_drv_gpio_irq(void);
void dvd_drv_dir_irq_in(void);
void dvd_drv_dir_irq_out(void);

void dvd_drv_init() {
    dvd_drv_init_gpios();

    // hold drive in reset and keep dir low
    gpio_set_outover(pin_dvd_reset, GPIO_OVERRIDE_LOW);
    gpio_set_outover(pin_dvd_dir, GPIO_OVERRIDE_LOW);

    dvd_drv_init_pio();

    // passthrough for dstrb
    {
        uint gpclk = 0;
        if      (pin_gc_dstrb == 21) gpclk = clk_gpout0;
        else if (pin_gc_dstrb == 23) gpclk = clk_gpout1;
        else if (pin_gc_dstrb == 24) gpclk = clk_gpout2;
        else if (pin_gc_dstrb == 25) gpclk = clk_gpout3;

        clocks_hw->clk[gpclk].div = 1 << CLOCKS_CLK_GPOUT0_DIV_INT_LSB;

        // set another clock source first so that the first clock cycles of dstrb are not missing
        clocks_hw->clk[gpclk].ctrl = (CLOCKS_CLK_GPOUT0_CTRL_AUXSRC_VALUE_XOSC_CLKSRC << CLOCKS_CLK_GPOUT0_CTRL_AUXSRC_LSB) | CLOCKS_CLK_GPOUT0_CTRL_ENABLE_BITS;
        sleep_us(10);
        clocks_hw->clk[gpclk].ctrl = (CLOCKS_CLK_GPOUT0_CTRL_AUXSRC_VALUE_CLKSRC_GPIN0 << CLOCKS_CLK_GPOUT0_CTRL_AUXSRC_LSB) | CLOCKS_CLK_GPOUT0_CTRL_ENABLE_BITS;
    }

    // dma for sending data
    send_chan = dma_claim_unused_channel(true);
    {
        dma_channel_config c = dma_channel_get_default_config(send_chan);
        channel_config_set_transfer_data_size(&c, DMA_SIZE_32);
        channel_config_set_dreq(&c, pio_get_dreq(pio0, PIO_SEND_SM, true));
        channel_config_set_read_increment(&c, true);
        channel_config_set_write_increment(&c, false);
        dma_channel_set_config(send_chan, &c, false);
        dma_channel_set_write_addr(send_chan, &pio0->txf[PIO_SEND_SM], false);
    }
    

    // gpio irq's for detecting a reset and break signal
    gpio_set_irq_enabled(pin_gc_reset, GPIO_IRQ_LEVEL_LOW, true);
    gpio_set_irq_enabled(pin_gc_brk, GPIO_IRQ_EDGE_RISE | GPIO_IRQ_EDGE_FALL, true);
    irq_set_exclusive_handler(IO_IRQ_BANK0, dvd_drv_gpio_irq);

    // irq handlers for direction changes
    irq_set_exclusive_handler(PIO0_IRQ_0, dvd_drv_dir_irq_in);
    irq_set_enabled(PIO0_IRQ_0, true);
    pio_set_irq0_source_enabled(pio0, PIO_INTR_SM0_LSB, true);
    irq_set_exclusive_handler(PIO0_IRQ_1, dvd_drv_dir_irq_out);
    irq_set_enabled(PIO0_IRQ_1, true);
    pio_set_irq1_source_enabled(pio0, PIO_INTR_SM1_LSB, true);


    // enable pull-down to check if a physical drive is present
    gpio_set_pulls(pin_dvd_dstrb, false, true);
    sleep_us(10);

    // close cover
    dvd_drv_set_cover(false);

    // start ode
    irq_set_enabled(IO_IRQ_BANK0, true);
    pio_enable_sm_mask_in_sync(pio0, (1 << PIO_RECV_SM) | (1 << PIO_SEND_SM) | (1 << PIO_DIR_SM));
}

void dvd_drv_init_gpios() {
    // gpios that are always inputs
    static uint8_t inputs[] = { pin_gc_dir, pin_hstrb, pin_dvd_dstrb, pin_dvd_err, pin_dvd_cover, pin_gc_reset };
    for (int i = 0; i < sizeof(inputs); i++) {
        gpio_set_function(inputs[i], GPIO_FUNC_PIO0);
        gpio_set_oeover(inputs[i], GPIO_OVERRIDE_LOW);
        pio_sm_set_consecutive_pindirs(pio0, 0, inputs[i], 1, false);
        gpio_set_pulls(inputs[i], false, false);
    }
    gpio_set_function(pin_dvd_dstrb, GPIO_FUNC_GPCK);
    gpio_set_pulls(pin_gc_reset, true, false);

    // gpios that are always outputs
    static uint8_t outputs[] = { pin_dvd_dir, pin_gc_dstrb, pin_gc_err, pin_gc_cover, pin_dvd_reset };
    for (int i = 0; i < sizeof(outputs); i++) {
        gpio_set_function(outputs[i], GPIO_FUNC_PIO0);
        gpio_set_oeover(outputs[i], GPIO_OVERRIDE_HIGH);
        pio_sm_set_consecutive_pindirs(pio0, 0, outputs[i], 1, true);
        gpio_set_pulls(outputs[i], false, false);
        gpio_set_slew_rate(outputs[i], GPIO_SLEW_RATE_FAST);
        gpio_set_drive_strength(outputs[i], GPIO_DRIVE_STRENGTH_12MA);
    }

    // gpios that are bidirectional
    static uint8_t bidirectionals[] = { pin_d0, pin_d1, pin_d2, pin_d3, pin_d4, pin_d5, pin_d6, pin_d7 };
    for (int i = 0; i < sizeof(bidirectionals); i++) {
        gpio_set_function(bidirectionals[i], GPIO_FUNC_PIO0);
        pio_sm_set_consecutive_pindirs(pio0, 0, bidirectionals[i], 1, false);
        gpio_set_pulls(bidirectionals[i], false, false);
        gpio_set_slew_rate(bidirectionals[i], GPIO_SLEW_RATE_FAST);
        gpio_set_drive_strength(bidirectionals[i], GPIO_DRIVE_STRENGTH_12MA);
    }

    // open drain gpios
    gpio_init(pin_gc_brk);
    gpio_set_outover(pin_gc_brk, GPIO_OVERRIDE_LOW);
    gpio_set_pulls(pin_gc_brk, false, false);
    gpio_set_oeover(pin_dvd_brk, GPIO_OVERRIDE_LOW); // currently not implemented
    gpio_set_pulls(pin_dvd_brk, false, false);
}
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

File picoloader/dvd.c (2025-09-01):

#include "dvd.h"

#include <stdio.h>
#include <stdbool.h>
#include <hardware/flash.h>
#include <pico/bootrom.h>
#include <pico/time.h>
#include <hardware/gpio.h>
#include "dvd_drv.h"

// 0: off 1: on 2: blink
static uint8_t led_state = 0;

static bool disable_on_rst = false;
static uint32_t last_error = 0;

static const uint8_t* disk_data;

static uint32_t flash_capacity = 0;
#define XIP_MAX (XIP_BASE + flash_capacity)

// include header data for dol files
asm("\
    .section .header, \"a\"\n\
    .incbin \"data/gbi.hdr\"\n\
    .incbin \"data/iso.hdr\"\n\
");
extern uint8_t data_header[];

// start of the actual payload
extern uint8_t data_payload[];

uint32_t get_flash_capacity();
bool dvd_is_valid_dol(const uint8_t* dol);

void dvd_init()
{
    gpio_init(PICO_DEFAULT_LED_PIN);
    gpio_set_dir(PICO_DEFAULT_LED_PIN, GPIO_OUT);
    led_state = 1;

    flash_capacity = get_flash_capacity();

    dvd_drv_init();

    // iso
    if (*(uint32_t*)&data_payload[0x1c] == 0x3d9f33c2) {
        disk_data = data_payload;
        return;
    }

    // dol
    if (dvd_is_valid_dol(data_payload)) {
        disk_data = data_header;
        return;
    }

    if (!dvd_drv_enable_passthrough()) {
        dvd_drv_set_cover(true);
    }
    led_state = 2;
}

uint32_t get_flash_capacity() {
    uint8_t txbuf[4] = {0x9f};
    uint8_t rxbuf[4] = {0};
    flash_do_cmd(txbuf, rxbuf, 4);
    return 1 << rxbuf[3];
}

bool dvd_is_valid_dol(const uint8_t* dol) {
    // check if the dol is bootable by ipl

    bool entrypoint_valid = false;
    uint32_t entrypoint = __builtin_bswap32(*(uint32_t*)&dol[0xe0]);

    uint32_t dol_size = 0;

    for (uint32_t i = 0; i < 18; i++) {
        uint32_t offset = __builtin_bswap32(*(uint32_t*)&dol[0x00 + 4*i]);
        if (offset != 0 && (offset & 0b11 || offset < 0x100))
            return false;

        uint32_t address = __builtin_bswap32(*(uint32_t*)&dol[0x48 + 4*i]);
        if (address != 0 && (address & 0b11 || address < 0x80000000 || address > 0x81200000))
            return false;

        uint32_t size = __builtin_bswap32(*(uint32_t*)&dol[0x90 + 4*i]);

        dol_size = MAX(dol_size, offset + size);

        // check if entrypoint is within a text segment
        if (i < 7 && entrypoint >= address && entrypoint < address + size)
            entrypoint_valid = true;
    }

    if (!entrypoint_valid)
        return false;

    uint32_t bss_address = __builtin_bswap32(*(uint32_t*)&dol[0xd8]);
    if (bss_address != 0 && bss_address < 0x80000000)
        return false;

    // reject if too small or too big
    if(dol_size < 0x100 || ((uint32_t)dol + dol_size) > XIP_MAX)
        return false;

    return true;
}

void dvd_request_custom(uint8_t *req);

void dvd_request(uint8_t *req)
{
    if (req == NULL) {
        dvd_drv_set_error();
        last_error = 0x040800;
        return;
    }

    switch(req[0]) {
        case 0x12: // inquiry
            static uint8_t drive_info[32] = { 0x00, 0x00, 0x00, 0x00, 0x00, 0x00, 0x00, 0x00, 0x00, 0x00, 0x00, 0x00 };
            dvd_drv_send(drive_info, sizeof(drive_info));
            break;

        case 0xA8: // read
            {
                disable_on_rst = true;

                uint32_t addr = __builtin_bswap32(*(uint32_t*)&req[4]) << 2;
                uint32_t len = __builtin_bswap32(*(uint32_t*)&req[8]) & ~0x1F;

                const uint8_t* dat = &disk_data[addr];
                if ((uint32_t)dat + len > XIP_MAX) {
                    dvd_drv_set_error();
                    last_error = 0x056300; // lead-out
                } else {
                    dvd_drv_send(dat, len);
                }
            }
            break;

        case 0xAB: // seek
            static uint8_t seek_resp[4] = { 0 };
            dvd_drv_send(seek_resp, sizeof(seek_resp));
            break;

        case 0xE0: // request error
            static uint8_t error_resp[4] = { 0 };
            *(uint32_t*)error_resp = __builtin_bswap32(last_error);
            error_resp[0] = 0; // status
            dvd_drv_send(error_resp, sizeof(error_resp));

            last_error = 0;
            break;

        case 0xE3: // stop motor
            static uint8_t motor_resp[4] = { 0 };
            dvd_drv_send(motor_resp, sizeof(motor_resp));
            break;

        case 0xE4: // audio buffer config
            static uint8_t audio_resp[4] = { 0 };
            dvd_drv_send(audio_resp, sizeof(audio_resp));
            break;

        case 0xF4: // custom command
            dvd_request_custom(req);
            break;

        default:
            dvd_drv_set_error();
            last_error = 0x052000;
            break;
    }
}

// custom commands
void dvd_request_custom(uint8_t *req) {
    switch(req[1]) {
        case 0x00: // device info
            static uint8_t device_info[32] = { 0x0D, 0x15, 0xE4, 0x5E, PROGRAM_VERSION_MAJOR, PROGRAM_VERSION_MINOR, 0x00, 0x00 }; // last two bytes are for future use
            dvd_drv_send(device_info, sizeof(device_info));
            break;

        case 0x01: // reboot into bootloader 
            reset_usb_boot(0, 0);
            break;

        default:
            dvd_drv_set_error();
            last_error = 0x052000;
            break;
    }
}

void dvd_reset()
{
    if (disable_on_rst) {
        dvd_drv_enable_passthrough();
    }
}

void dvd_task()
{
    switch(led_state) {
        case 0:
            gpio_put(PICO_DEFAULT_LED_PIN, false);
            break;
        case 1:
            gpio_put(PICO_DEFAULT_LED_PIN, true);
            break;
        case 2:
            gpio_put(PICO_DEFAULT_LED_PIN, time_us_64() & (1 << 19));
            break;
    }
}

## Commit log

2025-06-29 code cleanup and break pin test
2025-07-16 custom command to reboot into bootloader
    [dvd.c]
2025-07-25 added flex kicad project
    Interposer flex for PicoLoader
    [Flex.kicad_pcb, Flex.kicad_sch]
2025-07-25 added solder flex kicad project
    PicoLoader mobo solderflex option
    [Flex.kicad_pcb, Flex.kicad_sch]
2025-07-25 flex mount stls
    [Interposer_Mount_v1.4.stl, SolderFlex_Mount_Horizontal_v1.2.stl]
2025-07-25 solderflex pics
2025-07-26 updated silkscreen
2025-07-26 update silkscreen images
2025-07-26 status led
2025-07-29 folder rename
    [Interposer_Mount_v1.4.stl, SolderFlex_Mount_Horizontal_v1.2.stl]
2025-07-30 improvement in case of no payload and no drive
2025-07-31 add mount with screw holder
    [Interposer_Mountv1.7.stl]
2025-07-31 Delete mount/Interposer_Mount_v1.4.stl
    removing old mount without screw holder
    [Interposer_Mount_v1.4.stl]
2025-07-31 gerber rename
2025-08-01 version info in device info
2025-08-23 gerber example order images
    sample images on how what settings to have selected to order gerbers
2025-08-31 solderless galery images
    Added additional images to the README for better visualization.
2025-09-01 pico 2 support
2025-09-01 update pico sdk
2025-09-02 readme pico 2
    Updated component list to include Raspberry Pi Pico 2.
2025-09-14 added Panasonic Q flex gerbers and kicad project
    [Flex.kicad_pcb, Flex.kicad_sch]
2025-09-14 mount for Panasonic Q Flex
    [Panasonic_Q_MountV1.2.stl]
2025-09-14 Panasonic Q restructure
    [Flex.kicad_pcb, Flex.kicad_sch]
2025-09-22 list solderless variant in readme
2025-09-24 DVD Plug stl for driveless flex use
    [DVD PlugV1.1.stl]
2025-09-24 rename dvd plug
    [DVD_PlugV1.1.stl]
2025-12-01 fold key stl
    [Fold_KeyV1.2.stl]
2026-01-28 solderless module files
    [NSBFlex.kicad_pcb, NSBFlex.kicad_sch, NSB_MountV1.7.stl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]
